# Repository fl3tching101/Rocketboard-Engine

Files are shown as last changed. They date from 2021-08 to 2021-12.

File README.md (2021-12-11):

# Rocketboard-Engine
Board which carries the full brains/powerhouse of a keyboard.
<p align="center">
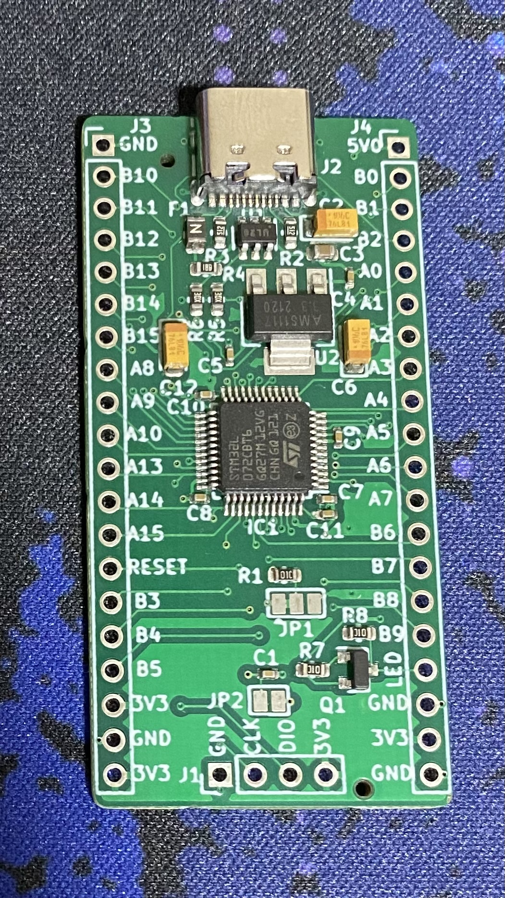
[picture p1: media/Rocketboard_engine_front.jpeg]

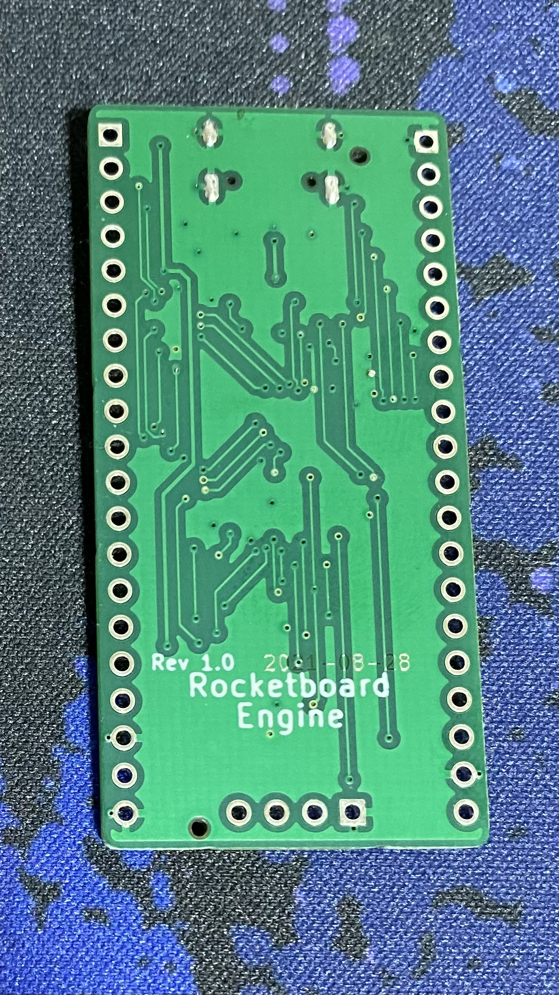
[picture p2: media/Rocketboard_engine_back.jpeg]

</p>

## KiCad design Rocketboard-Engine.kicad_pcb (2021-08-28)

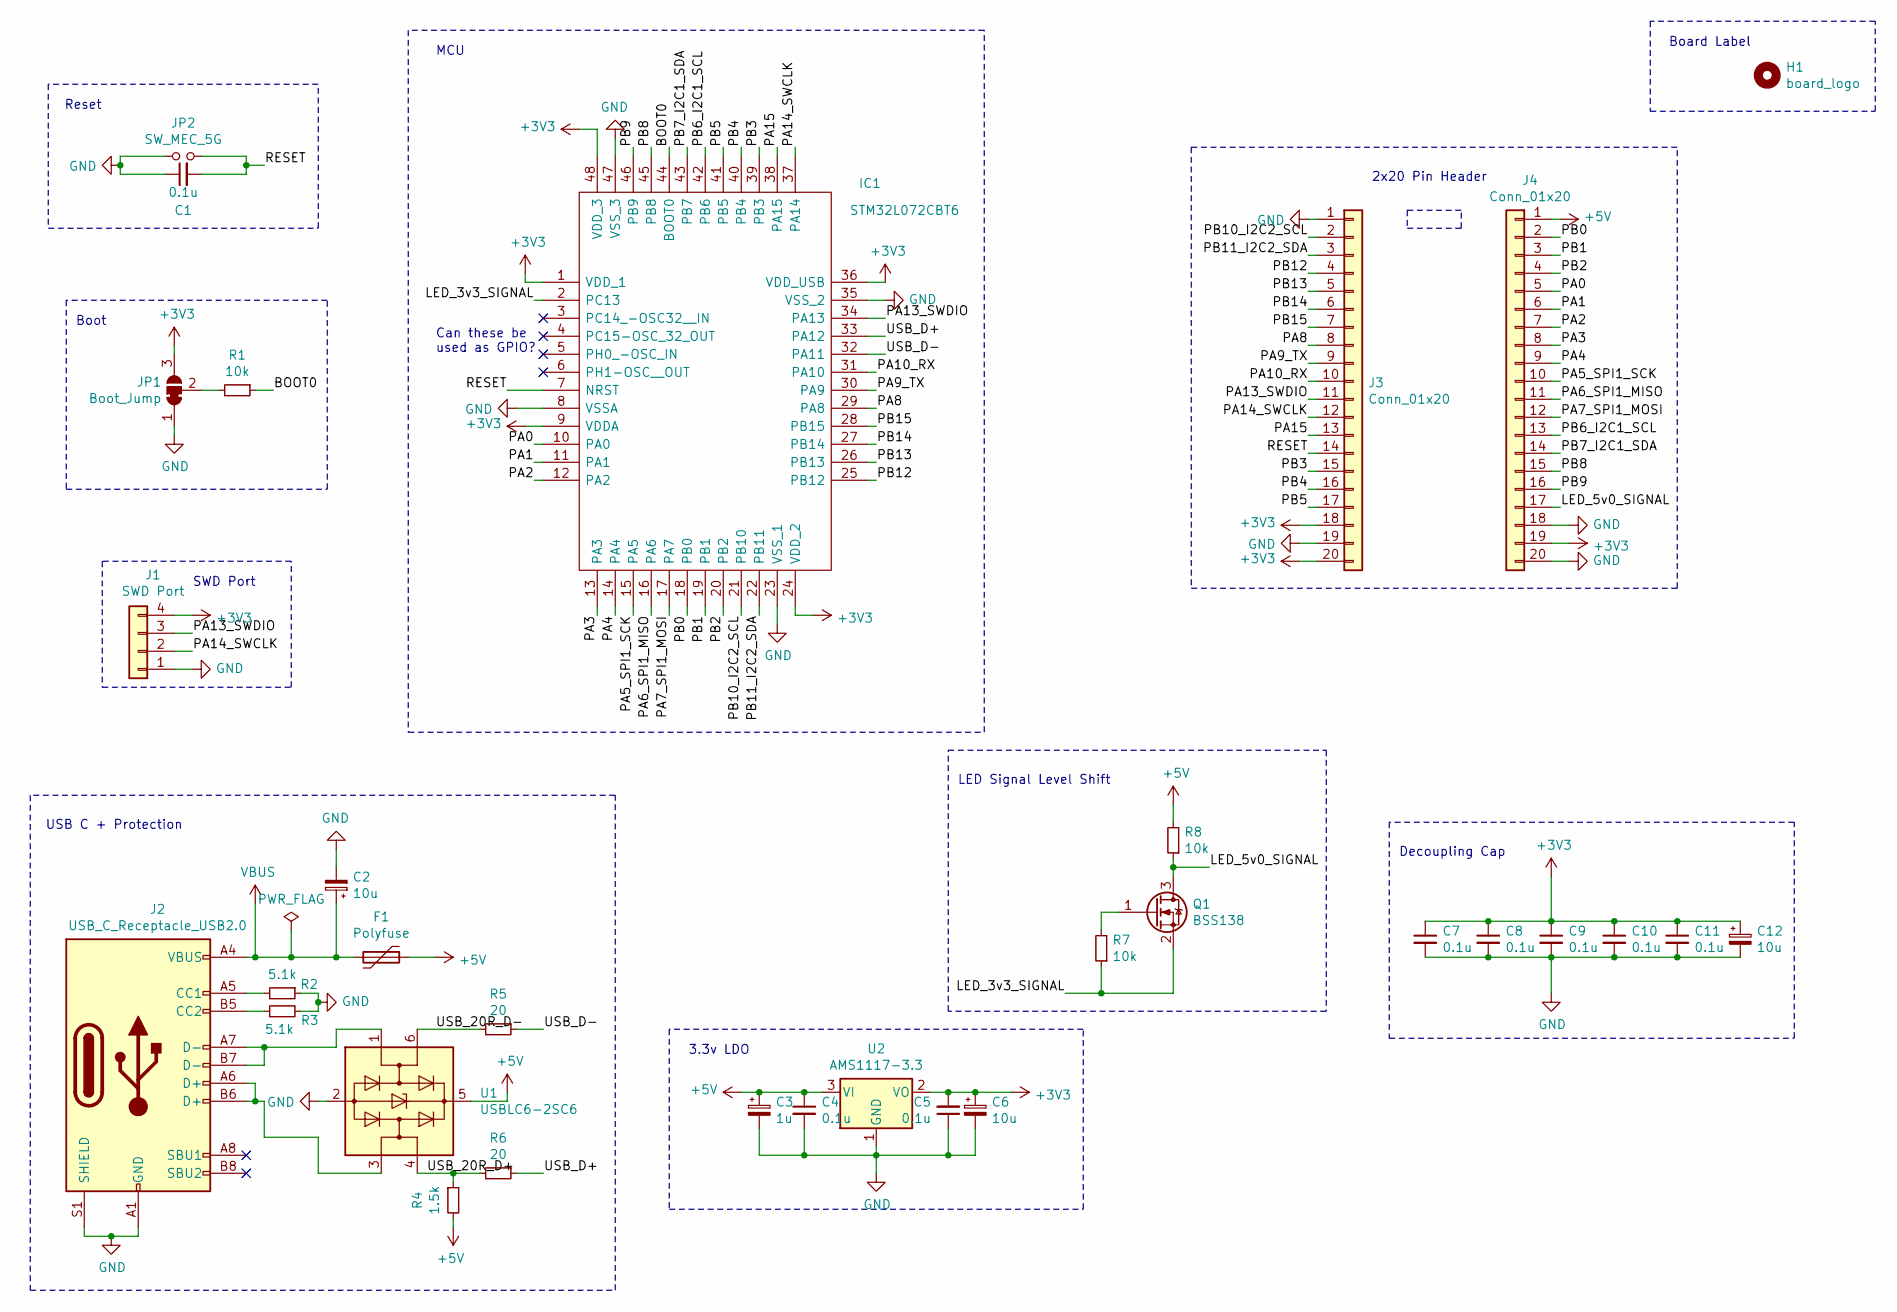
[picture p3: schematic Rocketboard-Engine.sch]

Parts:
C1, C4, C5, C7, C8, C9, C10, C11: 0.1u; C_0402_1005Metric
C2, C6, C12: 10u; CP_EIA-3216-10_Kemet-I
C3: 1u; C_0603_1608Metric
F1: Polyfuse; R_0805_2012Metric
H1: board_logo; board-title
IC1: STM32L072CBT6; LQFP-48_7x7mm_P0.5mm; Manufacturer_Part_Number STM32L072CBT6; Mouser Part Number 511-STM32L072CBT6
J1: SWD Port; PinHeader_1x04_P2.54mm_Vertical
J2: USB_C_Receptacle_USB2.0; USB_C_Receptacle_Palconn_UTC16-G
J3, J4: Conn_01x20; PinHeader_1x20_P2.54mm_Vertical
JP1: Boot_Jump; SolderJumper-3_P1.3mm_Bridged12_Pad1.0x1.5mm
JP2: SW_MEC_5G; SolderJumper-2_P1.3mm_Open_Pad1.0x1.5mm
Q1: BSS138; SOT-23
R1, R7, R8: 10k; R_0603_1608Metric
R2, R3: 5.1k; R_0603_1608Metric
R4: 1.5k; R_0603_1608Metric
R5, R6: 20; R_0603_1608Metric
U1: USBLC6-2SC6; SOT-23-6
U2: AMS1117-3.3; SOT-223-3_TabPin2

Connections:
+3V3: C5.2, C6.1, C7.1, C8.1, C9.1, C10.1, C11.1, C12.1, IC1.1 (VDD_1), IC1.9 (VDDA), IC1.24 (VDD_2), IC1.36 (VDD_USB), IC1.48 (VDD_3), J1.4, J3.18, J3.20, J4.19, JP1.3 (B), U2.2 (VO)
+5V: C3.1, C4.1, F1.1, J4.1, R4.2, R8.2, U1.5 (VBUS), U2.3 (VI)
/BOOT0: IC1.44 (BOOT0), R1.1
/LED_3v3_SIGNAL: IC1.2 (PC13), Q1.2 (S), R7.1
/LED_5v0_SIGNAL: J4.17, Q1.3 (D), R8.1
/PA0: IC1.10 (PA0), J4.5
/PA1: IC1.11 (PA1), J4.6
/PA2: IC1.12 (PA2), J4.7
/PA3: IC1.13 (PA3), J4.8
/PA4: IC1.14 (PA4), J4.9
/PA5_SPI1_SCK: IC1.15 (PA5), J4.10
/PA6_SPI1_MISO: IC1.16 (PA6), J4.11
/PA7_SPI1_MOSI: IC1.17 (PA7), J4.12
/PA8: IC1.29 (PA8), J3.8
/PA9_TX: IC1.30 (PA9), J3.9
/PA10_RX: IC1.31 (PA10), J3.10
/PA13_SWDIO: IC1.34 (PA13), J1.3, J3.11
/PA14_SWCLK: IC1.37 (PA14), J1.2, J3.12
/PA15: IC1.38 (PA15), J3.13
/PB0: IC1.18 (PB0), J4.2
/PB1: IC1.19 (PB1), J4.3
/PB2: IC1.20 (PB2), J4.4
/PB3: IC1.39 (PB3), J3.15
/PB4: IC1.40 (PB4), J3.16
/PB5: IC1.41 (PB5), J3.17
/PB6_I2C1_SCL: IC1.42 (PB6), J4.13
/PB7_I2C1_SDA: IC1.43 (PB7), J4.14
/PB8: IC1.45 (PB8), J4.15
/PB9: IC1.46 (PB9), J4.16
/PB10_I2C2_SCL: IC1.21 (PB10), J3.2
/PB11_I2C2_SDA: IC1.22 (PB11), J3.3
/PB12: IC1.25 (PB12), J3.4
/PB13: IC1.26 (PB13), J3.5
/PB14: IC1.27 (PB14), J3.6
/PB15: IC1.28 (PB15), J3.7
/RESET: C1.2, IC1.7 (NRST), J3.14, JP2.2
/USB_20R_D+: R4.1, R6.2, U1.4 (I/O2)
/USB_20R_D-: R5.2, U1.6 (I/O1)
/USB_D+: IC1.33 (PA12), R6.1
/USB_D-: IC1.32 (PA11), R5.1
GND: C1.1, C2.2, C3.2, C4.2, C5.1, C6.2, C7.2, C8.2, C9.2, C10.2, C11.2, C12.2, IC1.8 (VSSA), IC1.23 (VSS_1), IC1.35 (VSS_2), IC1.47 (VSS_3), J1.1, J2.A1 (GND), J2.A12 (GND), J2.B1 (GND), J2.B12 (GND), J2.S1 (SHIELD), J3.1, J3.19, J4.18, J4.20, JP1.1 (A), JP2.1, R2.1, R3.2, U1.2 (GND), U2.1 (GND)
unnamed: J2.A5 (CC1), R2.2
unnamed: J2.A6 (D+), J2.B6 (D+), U1.3 (I/O2)
unnamed: J2.A7 (D-), J2.B7 (D-), U1.1 (I/O1)
unnamed: J2.B5 (CC2), R3.1
unnamed: JP1.2 (C), R1.2
unnamed: Q1.1 (G), R7.2
VBUS: C2.1, F1.2, J2.A4 (VBUS), J2.A9 (VBUS), J2.B4 (VBUS), J2.B9 (VBUS)

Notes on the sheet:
3.3v LDO
USB C + Protection
Decoupling Cap
Reset
Boot
SWD Port
LED Signal Level Shift
Can these be used as GPIO?
MCU
2x20 Pin Header
Board Label

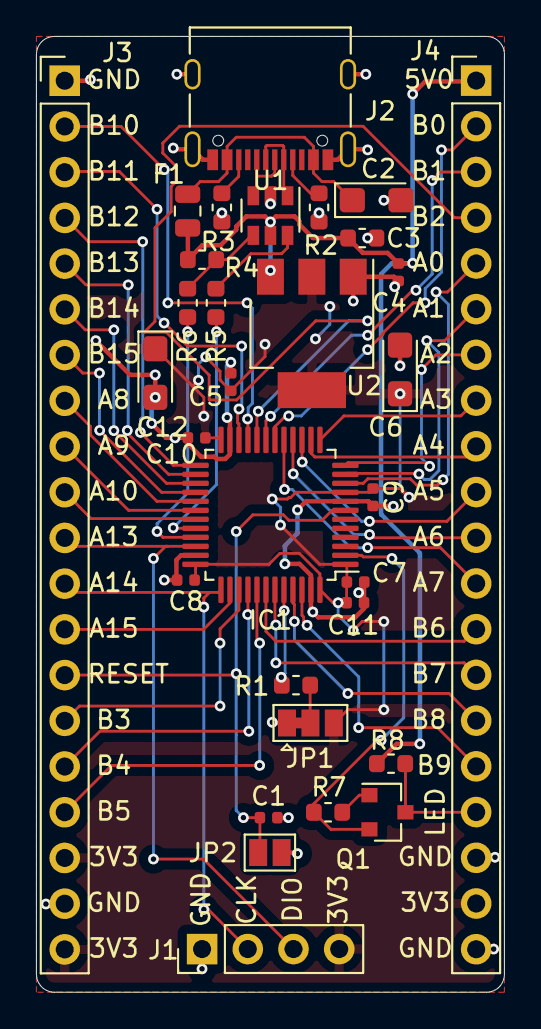
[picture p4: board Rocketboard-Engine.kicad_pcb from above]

Board: 2 copper layers, 26.0 x 53.1 mm, 32 parts (1 on the bottom side), 48 nets.

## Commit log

2021-08-28 Preliminary design done
    Preliminary design work is done for schematic and layout, and updated gitignore to catch everything. Design may still need some tweaks, but is overall good.
    [Rocketboard-Engine.kicad_pcb, Rocketboard-Engine.sch]
2021-08-28 Fixed unconnected copper pours/nets
    [Rocketboard-Engine.kicad_pcb]
2021-08-28 Added silkscreen, fixed some placements, and generated gerbers
    [Rocketboard-Engine-B_Cu.gbr, Rocketboard-Engine-B_Mask.gbr, Rocketboard-Engine-B_Paste.gbr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]
2021-08-28 Unknown change, but this is the state of ordered rev 1.0 boards
    [Rocketboard-Engine.sch]
2021-09-07 Deleted unused comment
    [Rocketboard-Engine.sch]
